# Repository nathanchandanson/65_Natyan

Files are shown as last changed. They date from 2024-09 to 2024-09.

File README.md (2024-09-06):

# 65_Natyan

The 65_Natyan is a custom 65% mechanical keyboard. It has individually addressable SK6812 led under each key. It is hotswappable and support both Cherry MX and Kailh Choc switches.

# Work in progress

This project is currently being developed, thus it is not sure that all will work.

## PCB

The Kicad project is accessible in the folder "pcb_files". You can open it to export the GERBER files and then order the PCB.

## Firmware

The firmware is based on [qmk_firmware](https://github.com/qmk/qmk_firmware). To flash the firmware, just follow the instructions given on the QMK docs.

## 3dModels

You can find the 3d models of the case I designed for this keyboard. 
To get it, you need to 3d print them, and wherever there is a hole for a fastener, you need to install a heat-press insert.

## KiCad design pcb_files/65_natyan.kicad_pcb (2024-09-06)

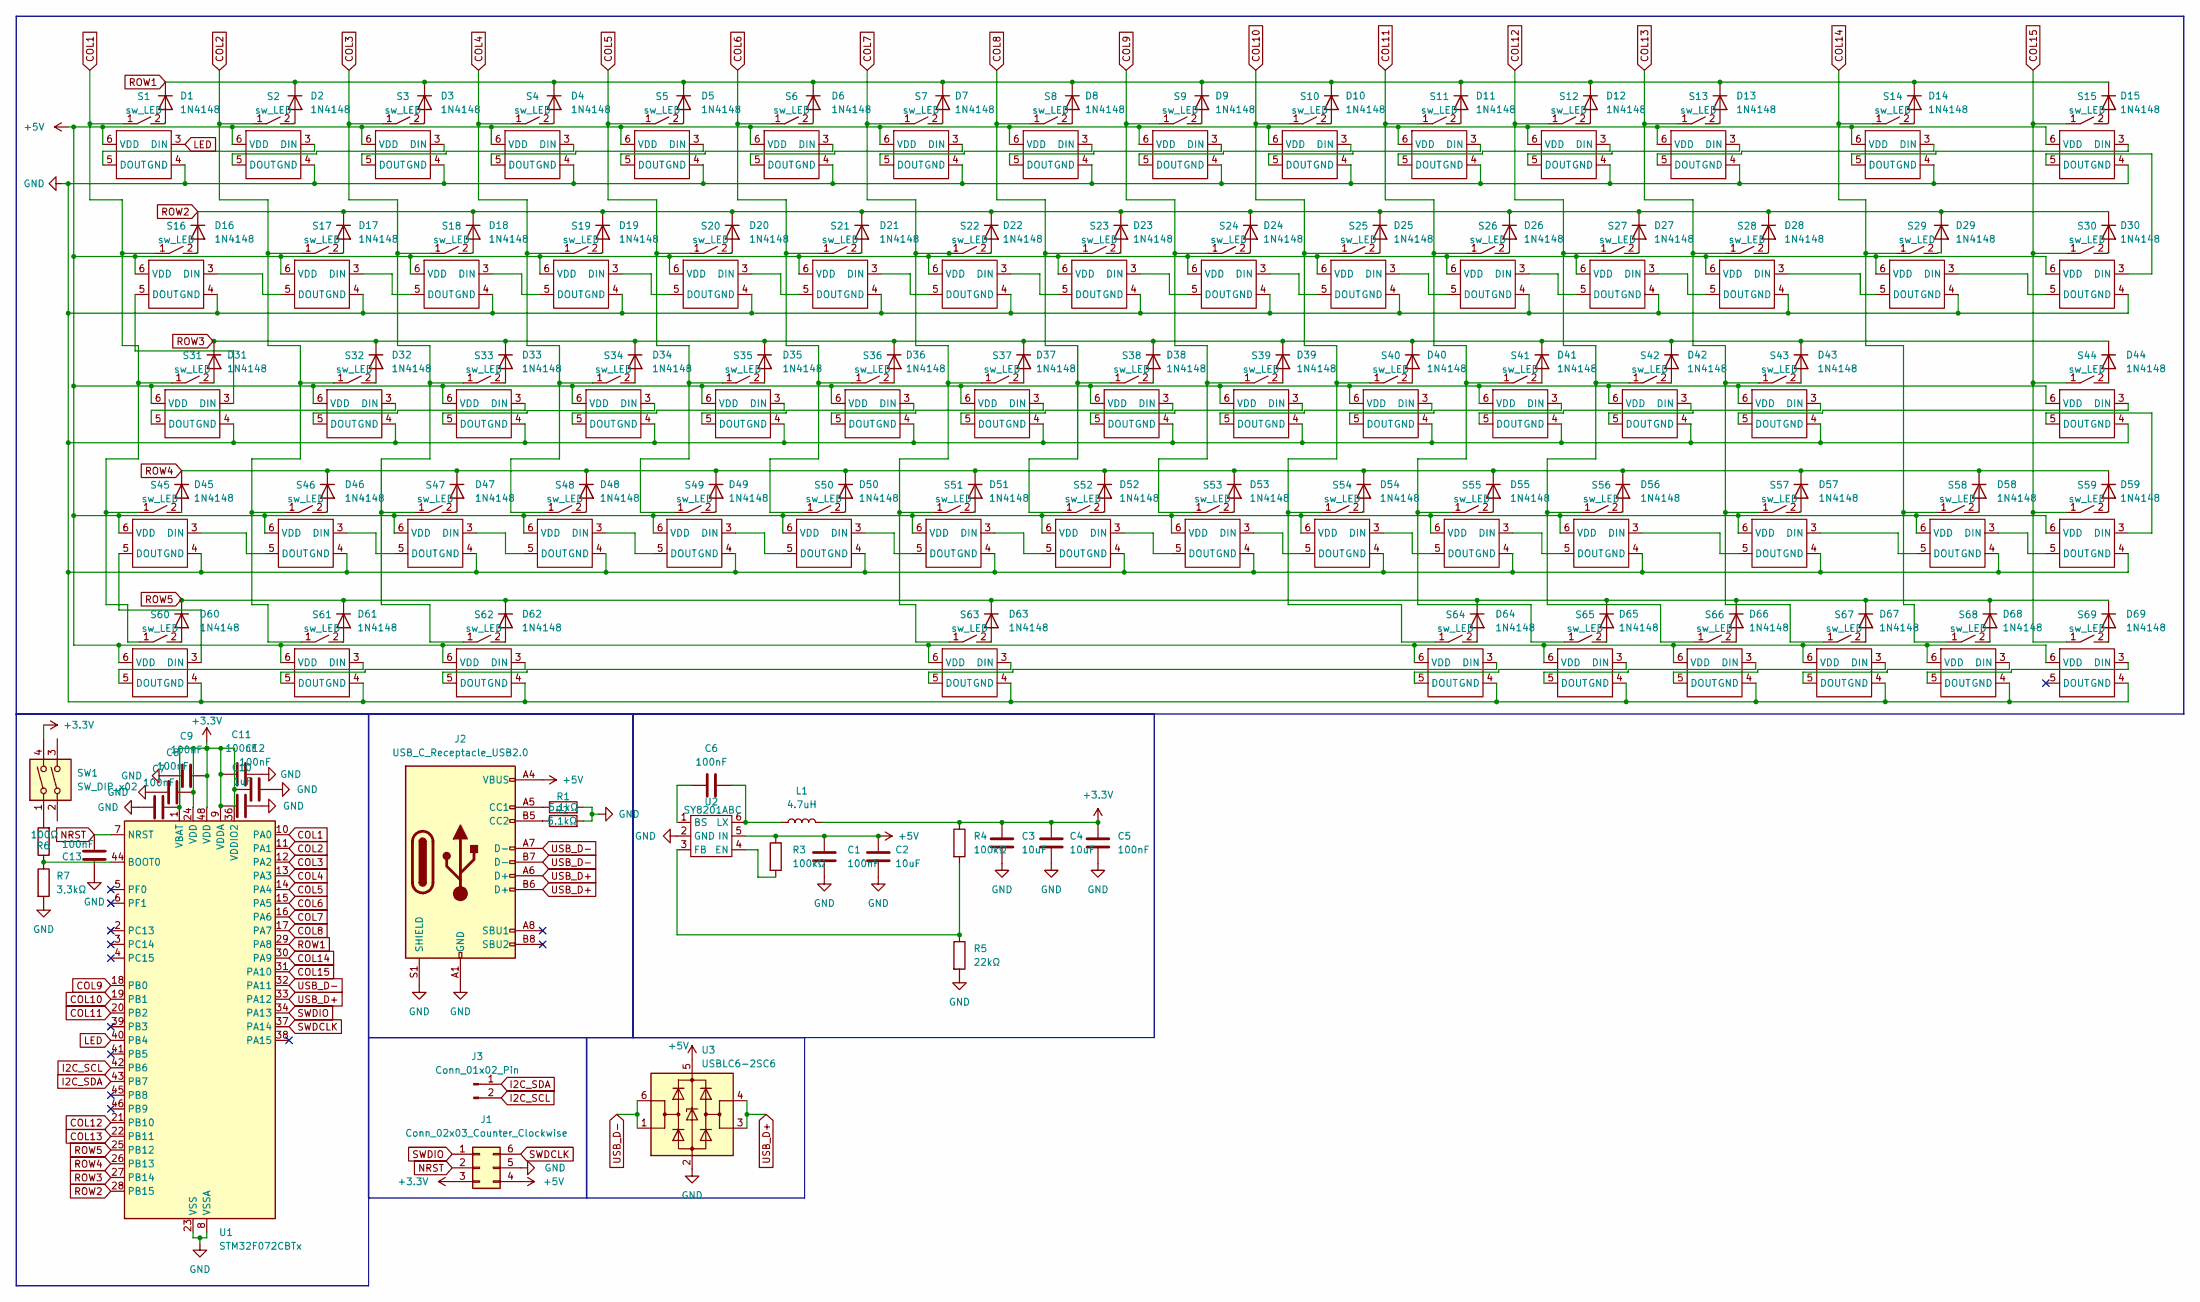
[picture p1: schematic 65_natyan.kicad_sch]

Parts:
C1, C5, C6, C7, C8, C9, C11, C12, C13: 100nF; C_0603_1608Metric_Pad1.08x0.95mm_HandSolder
C2, C3, C4: 10uF; C_0603_1608Metric_Pad1.08x0.95mm_HandSolder
C10: 1uF; C_0603_1608Metric_Pad1.08x0.95mm_HandSolder
D1, D2, D3, D4, D5, D6, D7, D8, D9, D10, D11, D12, D13, D14, D15, D16, D17, D18, D19, D20, D21, D22, D23, D24, D25, D26, D27, D28, D29, D30, D31, D32, D33, D34, D35, D36, D37, D38, D39, D40, D41, D42, D43, D44, D45, D46, D47, D48, D49, D50, D51, D52, D53, D54, D55, D56, D57, D58, D59, D60, D61, D62, D63, D64, D65, D66, D67, D68, D69: 1N4148; D_DO-35_SOD27_P7.62mm_Horizontal
J1: Conn_02x03_Counter_Clockwise; PinHeader_2x03_P2.54mm_Vertical
J2: USB_C_Receptacle_USB2.0; USB-C-SMD_KH-TYPE-C-16P
J3: Conn_01x02_Pin; PinHeader_1x02_P2.54mm_Vertical
L1: 4.7uH; L_0603_1608Metric_Pad1.05x0.95mm_HandSolder
R1, R2: 5.1kΩ; R_0603_1608Metric_Pad0.98x0.95mm_HandSolder
R3, R4: 100kΩ; R_0603_1608Metric_Pad0.98x0.95mm_HandSolder
R5: 22kΩ; R_0603_1608Metric_Pad0.98x0.95mm_HandSolder
R6: 100Ω; R_0603_1608Metric_Pad0.98x0.95mm_HandSolder
R7: 3,3kΩ; R_0603_1608Metric_Pad0.98x0.95mm_HandSolder
S1, S2, S3, S4, S5, S6, S7, S8, S9, S10, S11, S12, S13, S15, S17, S18, S19, S20, S21, S22, S23, S24, S25, S26, S27, S28, S30, S32, S33, S34, S35, S36, S37, S38, S39, S40, S41, S42, S43, S44, S46, S47, S48, S49, S50, S51, S52, S53, S54, S55, S56, S58, S59, S64, S65, S66, S67, S68, S69: sw_LED; sw_MX-Choc_Hotswap-underLED_1u
S14: sw_LED; sw_MX-Choc_Hotswap-underLED_2u
S16: sw_LED; sw_MX-Choc_Hotswap-underLED_1.5u
S29: sw_LED; sw_MX-Choc_Hotswap-underLED_isoEnter
S31, S57: sw_LED; sw_MX-Choc_Hotswap-underLED_1.75u
S45, S60, S61, S62: sw_LED; sw_MX-Choc_Hotswap-underLED_1.25u
S63: sw_LED; sw_MX-Choc_Hotswap-underLED_6,25u
SW1: SW_DIP_x02; rst_sw
U1: STM32F072CBTx; LQFP-48_7x7mm_P0.5mm
U2: SY8201ABC; SOT-23-6_Handsoldering
U3: USBLC6-2SC6; SOT-23-6_Handsoldering

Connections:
+3.3V: C3.1, C4.1, C5.1, C7.2, C8.1, C9.2, C10.1, C11.1, C12.1, J1.3, L1.2, R4.1, SW1.4, U1.1 (VBAT), U1.9 (VDDA), U1.24 (VDD), U1.36 (VDDIO2), U1.48 (VDD)
+5V: C1.1, C2.1, J1.4, J2.A4 (VBUS), J2.A9 (VBUS), J2.B4 (VBUS), J2.B9 (VBUS), R3.1, S1.6 (VDD), S2.6 (VDD), S3.6 (VDD), S4.6 (VDD), S5.6 (VDD), S6.6 (VDD), S7.6 (VDD), S8.6 (VDD), S9.6 (VDD), S10.6 (VDD), S11.6 (VDD), S12.6 (VDD), S13.6 (VDD), S14.6 (VDD), S15.6 (VDD), S16.6 (VDD), S17.6 (VDD), S18.6 (VDD), S19.6 (VDD), S20.6 (VDD), S21.6 (VDD), S22.6 (VDD), S23.6 (VDD), S24.6 (VDD), S25.6 (VDD), S26.6 (VDD), S27.6 (VDD), S28.6 (VDD), S29.6 (VDD), S30.6 (VDD), S31.6 (VDD), S32.6 (VDD), S33.6 (VDD), S34.6 (VDD), S35.6 (VDD), S36.6 (VDD), S37.6 (VDD), S38.6 (VDD), S39.6 (VDD), S40.6 (VDD), S41.6 (VDD), S42.6 (VDD), S43.6 (VDD), S44.6 (VDD), S45.6 (VDD), S46.6 (VDD), S47.6 (VDD), S48.6 (VDD), S49.6 (VDD), S50.6 (VDD), S51.6 (VDD), S52.6 (VDD), S53.6 (VDD), S54.6 (VDD), S55.6 (VDD), S56.6 (VDD), S57.6 (VDD), S58.6 (VDD), S59.6 (VDD), S60.6 (VDD), S61.6 (VDD), S62.6 (VDD), S63.6 (VDD), S64.6 (VDD), S65.6 (VDD), S66.6 (VDD), S67.6 (VDD), S68.6 (VDD), S69.6 (VDD), U2.5 (IN), U3.5 (VBUS)
COL1: S1.1, S16.1, S31.1, S45.1, S60.1, U1.10 (PA0)
COL2: S2.1, S17.1, S32.1, S46.1, S61.1, U1.11 (PA1)
COL3: S3.1, S18.1, S33.1, S47.1, S62.1, U1.12 (PA2)
COL4: S4.1, S19.1, S34.1, S48.1, U1.13 (PA3)
COL5: S5.1, S20.1, S35.1, S49.1, U1.14 (PA4)
COL6: S6.1, S21.1, S36.1, S50.1, U1.15 (PA5)
COL7: S7.1, S22.1, S37.1, S51.1, S63.1, U1.16 (PA6)
COL8: S8.1, S23.1, S38.1, S52.1, U1.17 (PA7)
COL9: S9.1, S24.1, S39.1, S53.1, U1.18 (PB0)
COL10: S10.1, S25.1, S40.1, S54.1, S64.1, U1.19 (PB1)
COL11: S11.1, S26.1, S41.1, S55.1, S65.1, U1.20 (PB2)
COL12: S12.1, S27.1, S42.1, S56.1, S66.1, U1.21 (PB10)
COL13: S13.1, S28.1, S43.1, S57.1, S67.1, U1.22 (PB11)
COL14: S14.1, S29.1, S58.1, S68.1, U1.30 (PA9)
COL15: S15.1, S30.1, S44.1, S59.1, S69.1, U1.31 (PA10)
GND: C1.2, C2.2, C3.2, C4.2, C5.2, C7.1, C8.2, C9.1, C10.2, C11.2, C12.2, C13.1, J1.5, J2.A1 (GND), J2.A12 (GND), J2.B1 (GND), J2.B12 (GND), J2.S1 (SHIELD), R1.2, R2.2, R5.2, R7.2, S1.4 (GND), S2.4 (GND), S3.4 (GND), S4.4 (GND), S5.4 (GND), S6.4 (GND), S7.4 (GND), S8.4 (GND), S9.4 (GND), S10.4 (GND), S11.4 (GND), S12.4 (GND), S13.4 (GND), S14.4 (GND), S15.4 (GND), S16.4 (GND), S17.4 (GND), S18.4 (GND), S19.4 (GND), S20.4 (GND), S21.4 (GND), S22.4 (GND), S23.4 (GND), S24.4 (GND), S25.4 (GND), S26.4 (GND), S27.4 (GND), S28.4 (GND), S29.4 (GND), S30.4 (GND), S31.4 (GND), S32.4 (GND), S33.4 (GND), S34.4 (GND), S35.4 (GND), S36.4 (GND), S37.4 (GND), S38.4 (GND), S39.4 (GND), S40.4 (GND), S41.4 (GND), S42.4 (GND), S43.4 (GND), S44.4 (GND), S45.4 (GND), S46.4 (GND), S47.4 (GND), S48.4 (GND), S49.4 (GND), S50.4 (GND), S51.4 (GND), S52.4 (GND), S53.4 (GND), S54.4 (GND), S55.4 (GND), S56.4 (GND), S57.4 (GND), S58.4 (GND), S59.4 (GND), S60.4 (GND), S61.4 (GND), S62.4 (GND), S63.4 (GND), S64.4 (GND), S65.4 (GND), S66.4 (GND), S67.4 (GND), S68.4 (GND), S69.4 (GND), U1.8 (VSSA), U1.23 (VSS), U1.35 (VSS), U1.47 (VSS), U2.2 (GND), U3.2 (GND)
I2C_SCL: J3.2, U1.42 (PB6)
I2C_SDA: J3.1, U1.43 (PB7)
LED: S1.3 (DIN), U1.40 (PB4)
NRST: C13.2, J1.2, U1.7 (NRST)
unnamed: D1.2 (A), S1.2
unnamed: D2.2 (A), S2.2
unnamed: D3.2 (A), S3.2
unnamed: D4.2 (A), S4.2
unnamed: D5.2 (A), S5.2
unnamed: D6.2 (A), S6.2
unnamed: D7.2 (A), S7.2
unnamed: D8.2 (A), S8.2
unnamed: D9.2 (A), S9.2
unnamed: D10.2 (A), S10.2
unnamed: D11.2 (A), S11.2
unnamed: D12.2 (A), S12.2
unnamed: D13.2 (A), S13.2
unnamed: D14.2 (A), S14.2
unnamed: D15.2 (A), S15.2
unnamed: D16.2 (A), S16.2
unnamed: D17.2 (A), S17.2
unnamed: D18.2 (A), S18.2
unnamed: D19.2 (A), S19.2
unnamed: D20.2 (A), S20.2
unnamed: D21.2 (A), S21.2
unnamed: D22.2 (A), S22.2
unnamed: D23.2 (A), S23.2
unnamed: D24.2 (A), S24.2
unnamed: D25.2 (A), S25.2
unnamed: D26.2 (A), S26.2
unnamed: D27.2 (A), S27.2
unnamed: D28.2 (A), S28.2
unnamed: D29.2 (A), S29.2
unnamed: D30.2 (A), S30.2
unnamed: D31.2 (A), S31.2
unnamed: D32.2 (A), S32.2
unnamed: D33.2 (A), S33.2
unnamed: D34.2 (A), S34.2
unnamed: D35.2 (A), S35.2
unnamed: D36.2 (A), S36.2
unnamed: D37.2 (A), S37.2
unnamed: D38.2 (A), S38.2
unnamed: D39.2 (A), S39.2
unnamed: D40.2 (A), S40.2
unnamed: D41.2 (A), S41.2
unnamed: D42.2 (A), S42.2
unnamed: D43.2 (A), S43.2
unnamed: D44.2 (A), S44.2
unnamed: D45.2 (A), S45.2
unnamed: D46.2 (A), S46.2
unnamed: D47.2 (A), S47.2
unnamed: D48.2 (A), S48.2
unnamed: D49.2 (A), S49.2
unnamed: D50.2 (A), S50.2
unnamed: D51.2 (A), S51.2
unnamed: D52.2 (A), S52.2
unnamed: D53.2 (A), S53.2
unnamed: D54.2 (A), S54.2
unnamed: D55.2 (A), S55.2
unnamed: D56.2 (A), S56.2
unnamed: D57.2 (A), S57.2
unnamed: D58.2 (A), S58.2
unnamed: D59.2 (A), S59.2
unnamed: D60.2 (A), S60.2
unnamed: D61.2 (A), S61.2
unnamed: D62.2 (A), S62.2
unnamed: D63.2 (A), S63.2
unnamed: D64.2 (A), S64.2
unnamed: D65.2 (A), S65.2
unnamed: D66.2 (A), S66.2
unnamed: D67.2 (A), S67.2
unnamed: D68.2 (A), S68.2
unnamed: D69.2 (A), S69.2
unnamed: J2.A5 (CC1), R1.1
unnamed: J2.B5 (CC2), R2.1
unnamed: R6.2, SW1.1
unnamed: S1.5 (DOUT), S2.3 (DIN)
unnamed: S2.5 (DOUT), S3.3 (DIN)
unnamed: S3.5 (DOUT), S4.3 (DIN)
unnamed: S4.5 (DOUT), S5.3 (DIN)
unnamed: S5.5 (DOUT), S6.3 (DIN)
unnamed: S6.5 (DOUT), S7.3 (DIN)
unnamed: S7.5 (DOUT), S8.3 (DIN)
unnamed: S8.5 (DOUT), S9.3 (DIN)
unnamed: S9.5 (DOUT), S10.3 (DIN)
unnamed: S10.5 (DOUT), S11.3 (DIN)
unnamed: S11.5 (DOUT), S12.3 (DIN)
unnamed: S12.5 (DOUT), S13.3 (DIN)
unnamed: S13.5 (DOUT), S14.3 (DIN)
unnamed: S14.5 (DOUT), S15.3 (DIN)
unnamed: S15.5 (DOUT), S30.3 (DIN)
unnamed: S16.3 (DIN), S17.5 (DOUT)
unnamed: S16.5 (DOUT), S31.3 (DIN)
unnamed: S17.3 (DIN), S18.5 (DOUT)
unnamed: S18.3 (DIN), S19.5 (DOUT)
unnamed: S19.3 (DIN), S20.5 (DOUT)
unnamed: S20.3 (DIN), S21.5 (DOUT)
unnamed: S21.3 (DIN), S22.5 (DOUT)
unnamed: S22.3 (DIN), S23.5 (DOUT)
unnamed: S23.3 (DIN), S24.5 (DOUT)
unnamed: S24.3 (DIN), S25.5 (DOUT)
unnamed: S25.3 (DIN), S26.5 (DOUT)
unnamed: S26.3 (DIN), S27.5 (DOUT)
unnamed: S27.3 (DIN), S28.5 (DOUT)
unnamed: S28.3 (DIN), S29.5 (DOUT)
unnamed: S29.3 (DIN), S30.5 (DOUT)
unnamed: S31.5 (DOUT), S32.3 (DIN)
unnamed: S32.5 (DOUT), S33.3 (DIN)
unnamed: S33.5 (DOUT), S34.3 (DIN)
unnamed: S34.5 (DOUT), S35.3 (DIN)
unnamed: S35.5 (DOUT), S36.3 (DIN)
unnamed: S36.5 (DOUT), S37.3 (DIN)
unnamed: S37.5 (DOUT), S38.3 (DIN)
unnamed: S38.5 (DOUT), S39.3 (DIN)
unnamed: S39.5 (DOUT), S40.3 (DIN)
unnamed: S40.5 (DOUT), S41.3 (DIN)
unnamed: S41.5 (DOUT), S42.3 (DIN)
unnamed: S42.5 (DOUT), S43.3 (DIN)
unnamed: S43.5 (DOUT), S44.3 (DIN)
unnamed: S44.5 (DOUT), S59.3 (DIN)
unnamed: S45.3 (DIN), S46.5 (DOUT)
unnamed: S45.5 (DOUT), S60.3 (DIN)
unnamed: S46.3 (DIN), S47.5 (DOUT)
unnamed: S47.3 (DIN), S48.5 (DOUT)
unnamed: S48.3 (DIN), S49.5 (DOUT)
unnamed: S49.3 (DIN), S50.5 (DOUT)
unnamed: S50.3 (DIN), S51.5 (DOUT)
unnamed: S51.3 (DIN), S52.5 (DOUT)
unnamed: S52.3 (DIN), S53.5 (DOUT)
unnamed: S53.3 (DIN), S54.5 (DOUT)
unnamed: S54.3 (DIN), S55.5 (DOUT)
unnamed: S55.3 (DIN), S56.5 (DOUT)
unnamed: S56.3 (DIN), S57.5 (DOUT)
unnamed: S57.3 (DIN), S58.5 (DOUT)
unnamed: S58.3 (DIN), S59.5 (DOUT)
unnamed: S60.5 (DOUT), S61.3 (DIN)
unnamed: S61.5 (DOUT), S62.3 (DIN)
unnamed: S62.5 (DOUT), S63.3 (DIN)
unnamed: S63.5 (DOUT), S64.3 (DIN)
unnamed: S64.5 (DOUT), S65.3 (DIN)
unnamed: S65.5 (DOUT), S66.3 (DIN)
unnamed: S66.5 (DOUT), S67.3 (DIN)
unnamed: S67.5 (DOUT), S68.3 (DIN)
unnamed: S68.5 (DOUT), S69.3 (DIN)
unnamed: R6.1, R7.1, U1.44 (BOOT0)
unnamed: C6.1, U2.1 (BS)
unnamed: R3.2, U2.4 (EN)
unnamed: R4.2, R5.1, U2.3 (FB)
unnamed: C6.2, L1.1, U2.6 (LX)
ROW1: D1.1 (K), D2.1 (K), D3.1 (K), D4.1 (K), D5.1 (K), D6.1 (K), D7.1 (K), D8.1 (K), D9.1 (K), D10.1 (K), D11.1 (K), D12.1 (K), D13.1 (K), D14.1 (K), D15.1 (K), U1.29 (PA8)
ROW2: D16.1 (K), D17.1 (K), D18.1 (K), D19.1 (K), D20.1 (K), D21.1 (K), D22.1 (K), D23.1 (K), D24.1 (K), D25.1 (K), D26.1 (K), D27.1 (K), D28.1 (K), D29.1 (K), D30.1 (K), U1.28 (PB15)
ROW3: D31.1 (K), D32.1 (K), D33.1 (K), D34.1 (K), D35.1 (K), D36.1 (K), D37.1 (K), D38.1 (K), D39.1 (K), D40.1 (K), D41.1 (K), D42.1 (K), D43.1 (K), D44.1 (K), U1.27 (PB14)
ROW4: D45.1 (K), D46.1 (K), D47.1 (K), D48.1 (K), D49.1 (K), D50.1 (K), D51.1 (K), D52.1 (K), D53.1 (K), D54.1 (K), D55.1 (K), D56.1 (K), D57.1 (K), D58.1 (K), D59.1 (K), U1.26 (PB13)
ROW5: D60.1 (K), D61.1 (K), D62.1 (K), D63.1 (K), D64.1 (K), D65.1 (K), D66.1 (K), D67.1 (K), D68.1 (K), D69.1 (K), U1.25 (PB12)
SWDCLK: J1.6, U1.37 (PA14)
SWDIO: J1.1, U1.34 (PA13)
USB_D+: J2.A6 (D+), J2.B6 (D+), U1.33 (PA12), U3.3 (I/O2), U3.4 (I/O2)
USB_D-: J2.A7 (D-), J2.B7 (D-), U1.32 (PA11), U3.1 (I/O1), U3.6 (I/O1)

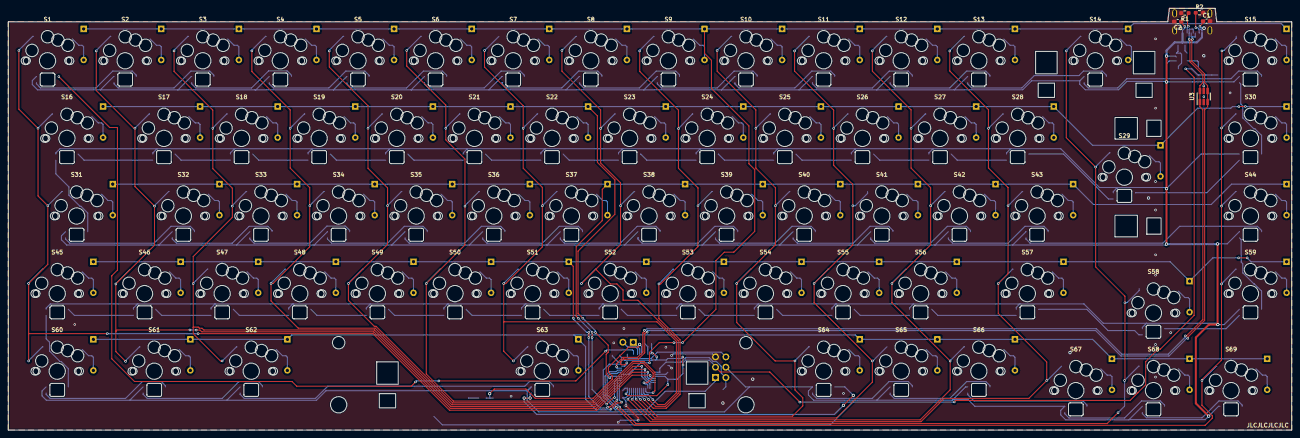
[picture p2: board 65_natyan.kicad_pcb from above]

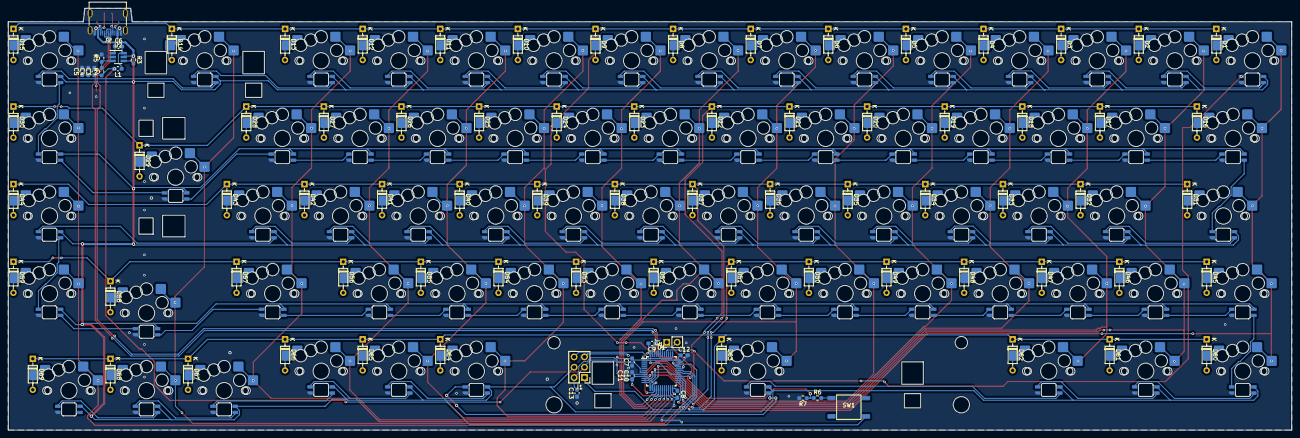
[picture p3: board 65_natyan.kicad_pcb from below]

Board: 2 copper layers, 315.0 x 103.5 mm, 166 parts (92 on the bottom side), 176 nets.

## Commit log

2024-09-06 PCB files
    Added the Kicad project files.
    [65_natyan.kicad_pcb, 65_natyan.kicad_sch]
2025-09-29 Added the footprint libraries
